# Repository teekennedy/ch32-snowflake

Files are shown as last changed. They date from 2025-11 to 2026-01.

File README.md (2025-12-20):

# CH32 Snowflake

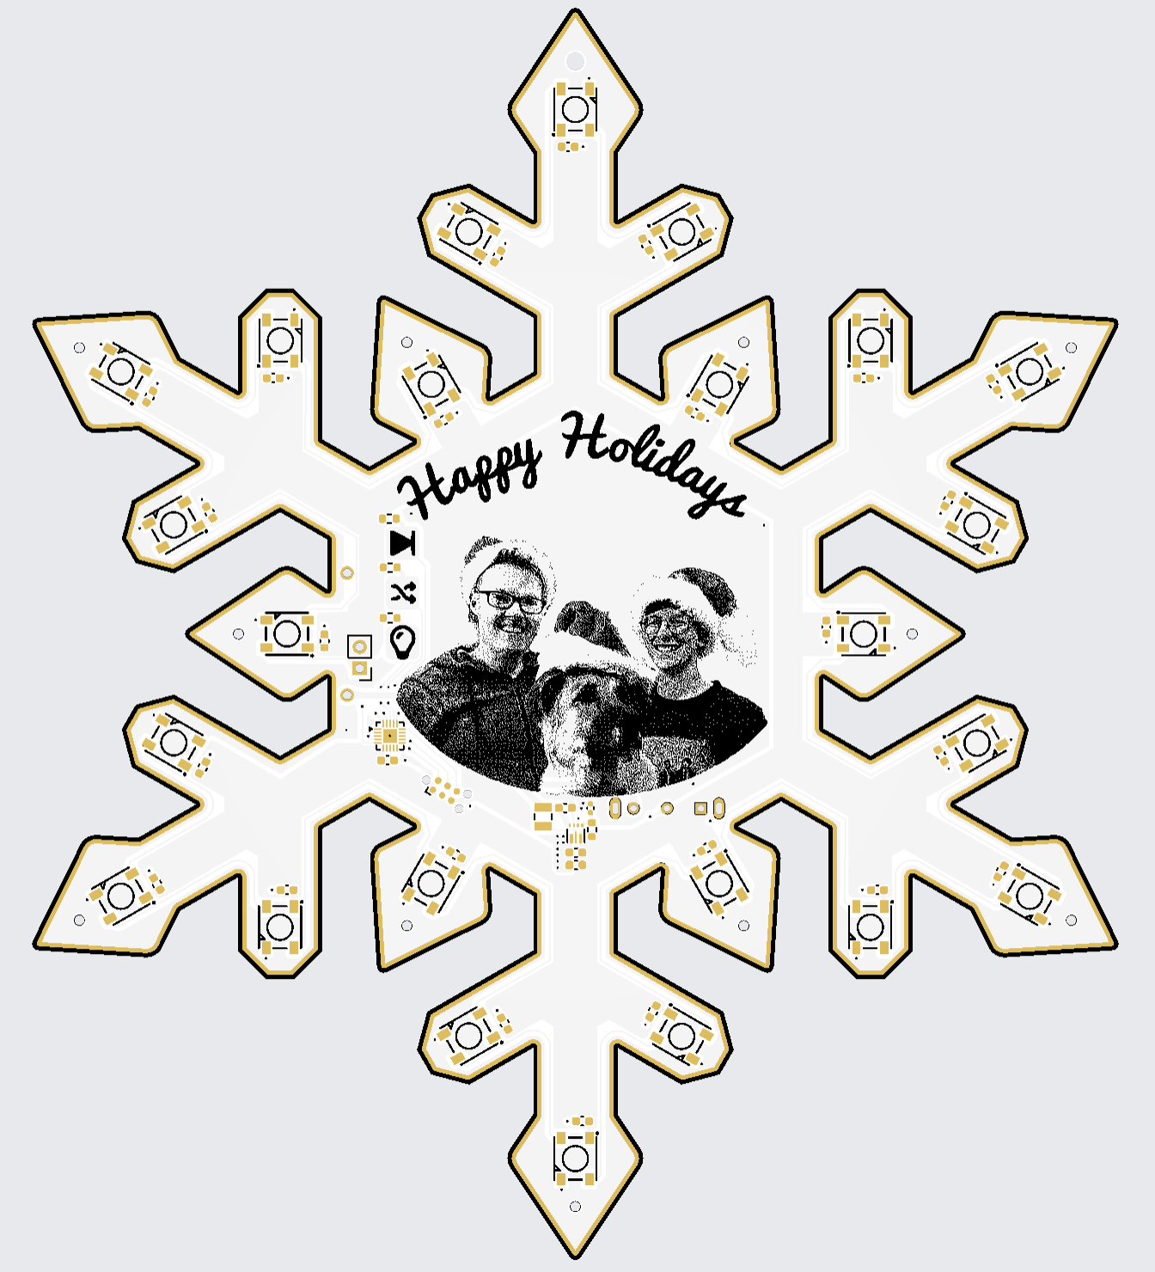
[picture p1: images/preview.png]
preview


A holiday snowflake with RGB LEDs, driven by the infamous CH32V003 microcontroller.

This is my first ever PCB design, and I borrowed heavily from [ch32-fireplace](https://github.com/johanwheeler/ch32-fireplace/tree/main) for snippets of schematic and code.

## PCB Shape

The snowflake shape was designed in OpenSCAD using the [BOSL2 library](https://github.com/BelfrySCAD/BOSL2).
If you want to view or make changes to the shape, I highly recommend installing the nightly version of openSCAD.

## KiCad Project

The KiCad project was designed with help from the [jlcpcb-tools plugin](https://github.com/Bouni/kicad-jlcpcb-tools).
If you plan to send this board to JLCPCB, be sure to import [corrections.csv](./board/jlcpcb/corrections.csv) before generating your pick and place file.
It has corrections for both the CH32V003 (90 degrees CCW rotation) and the TPS61002 boost converter (which is offset from where it should be).

I did my best to choose Basic parts where possible, to help keep the cost of the economic PCB assembly down.
Then I went with an ENIG coating and couldn't use economic PCBA anyway. Oh well.

## Firmware

In order to flash the firmware, you need to setup your build environment for [ch32fun](https://github.com/cnlohr/ch32fun).
See [their installation wiki](https://github.com/cnlohr/ch32fun/wiki/Installation) for instructions.

Next, build the `minichlink` utility.
Ensure the ch32fun submodule is initialized `git submodule update --init`.
Then, from the software/ch32fun/minichlink directory, run `make`.
If you have your RISC-V toolchain installed properly, it should build.

Now you can go to the software/src directory and run `make` to compile and flash the binary.

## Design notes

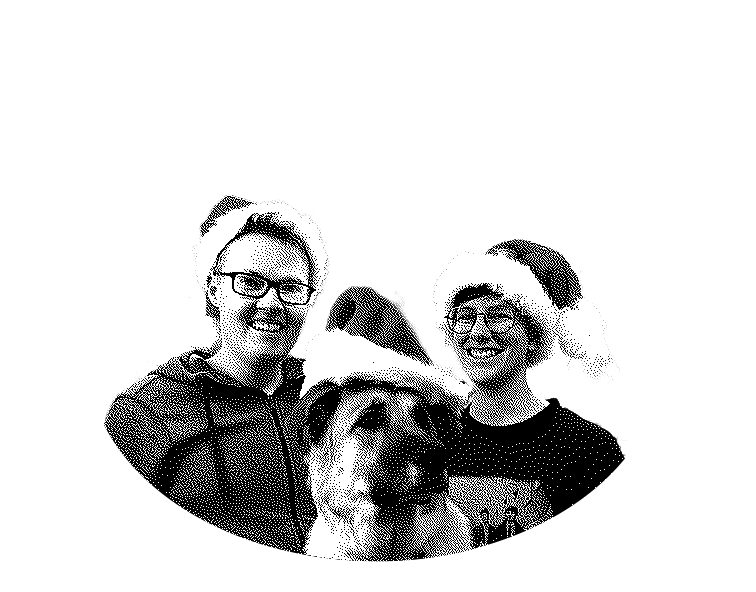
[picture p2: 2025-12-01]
images/graphics/front-silkscreen-ditherlicious.png

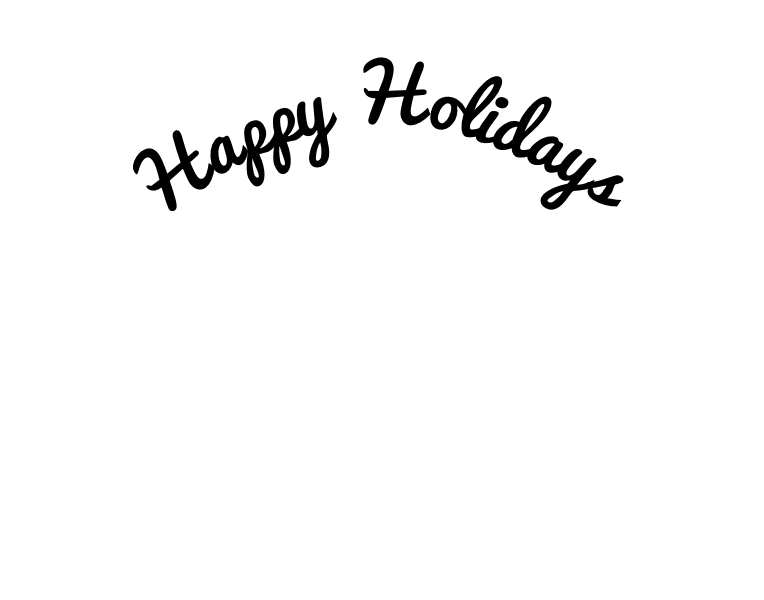
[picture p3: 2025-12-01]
images/graphics/front-silkscreen-text.png

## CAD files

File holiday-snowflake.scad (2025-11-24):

include <BOSL2/std.scad>

//visualization options
show_leds = false;
show_halos = false;
show_board = true;

$fn=16;

PHI = (1 + sqrt(5)) / 2; // =~ 1.618

branch_thickness = 10;
// shrinking overall diameter to account for diamond shapes added at tips
base_diameter = 150;
diameter = base_diameter - (branch_thickness * 1.2 * sqrt(2) * 1.5);
radius = diameter / 2;
secondary_branch_1_offset = radius*0.65;
secondary_branch_1_length = radius/3;

chamfer = branch_thickness / 3;
middle_diameter = 34;

// --- LED + halo params ---
led_size       = [5,5];
led_color      = "lightblue";
halo_color     = "lightyellow";   // outline color
halo_diameter  = middle_diameter/1.5;            // diameter of brightness ring
halo_width     = 0.8;           // thickness of the ring

// Module: centered LED with a thin circular outline ("brightness" halo)
module led_with_halo(
    size      = led_size,
    led_col   = led_color,
    halo_col  = halo_color,
    halo_d    = halo_diameter,
    halo_w    = halo_width
){
    up(1) {
        // LED body (centered rectangle)
        if (show_leds) color(led_col) rect(size);

        // Thin ring made by subtracting a slightly smaller circle
        halo_path = circle(d=halo_d);
        if (show_halos) color(halo_col) stroke(halo_path,closed=true);
    }
}

// the central hexagon of the snowflake
module central_hexagon(diameter) {
    if(show_board)
        regular_ngon(6, diameter);
//    rot_copies(n=6)
//        right(diameter - branch_thickness/PHI) led_with_halo();
}

module primary_branch(
    length,
){
    if(show_board) {
        rect([length, branch_thickness], anchor=LEFT);
        right(length) xscale(1.5) rect(branch_thickness*1.2, spin=45, rounding=1);
    }
    right(length) led_with_halo();
}

module secondary_branch(
    offset,
    length,
    led=true,
){
    if(show_board)
        for(ang=[60,-60])
            right(offset)
                rect([length, branch_thickness], chamfer=[chamfer,0,0,chamfer],spin=ang, anchor=LEFT);
    if (led)
        for(ang=[60,-60])
            right(offset)
                zrot(ang)
                    right(cos(ang)*length*2 - branch_thickness/PHI)
                        led_with_halo();
}

// When importing the LEDs into KiCAD (for easier alignment), the scale is somehow different from the snowflake.
// Adding these markings in the corners so both exports have the same bounding box.
//for(x=[base_diameter / -2, base_diameter / 2]) {
//    for(y=[base_diameter / -2, base_diameter / 2]) {
//        left(x) back(y) rect(0.2);
//    }
//}
// Rotated so it has vertical primary branches.
// This will make it easier to address the LEDs starting with the "North" branch.
zrot(90) {
    central_hexagon(middle_diameter);
    rot_copies(n=6) {
        primary_branch(radius);
        zrot(30) primary_branch(radius*1.1/2);
        secondary_branch(secondary_branch_1_offset, secondary_branch_1_length);
    }
}

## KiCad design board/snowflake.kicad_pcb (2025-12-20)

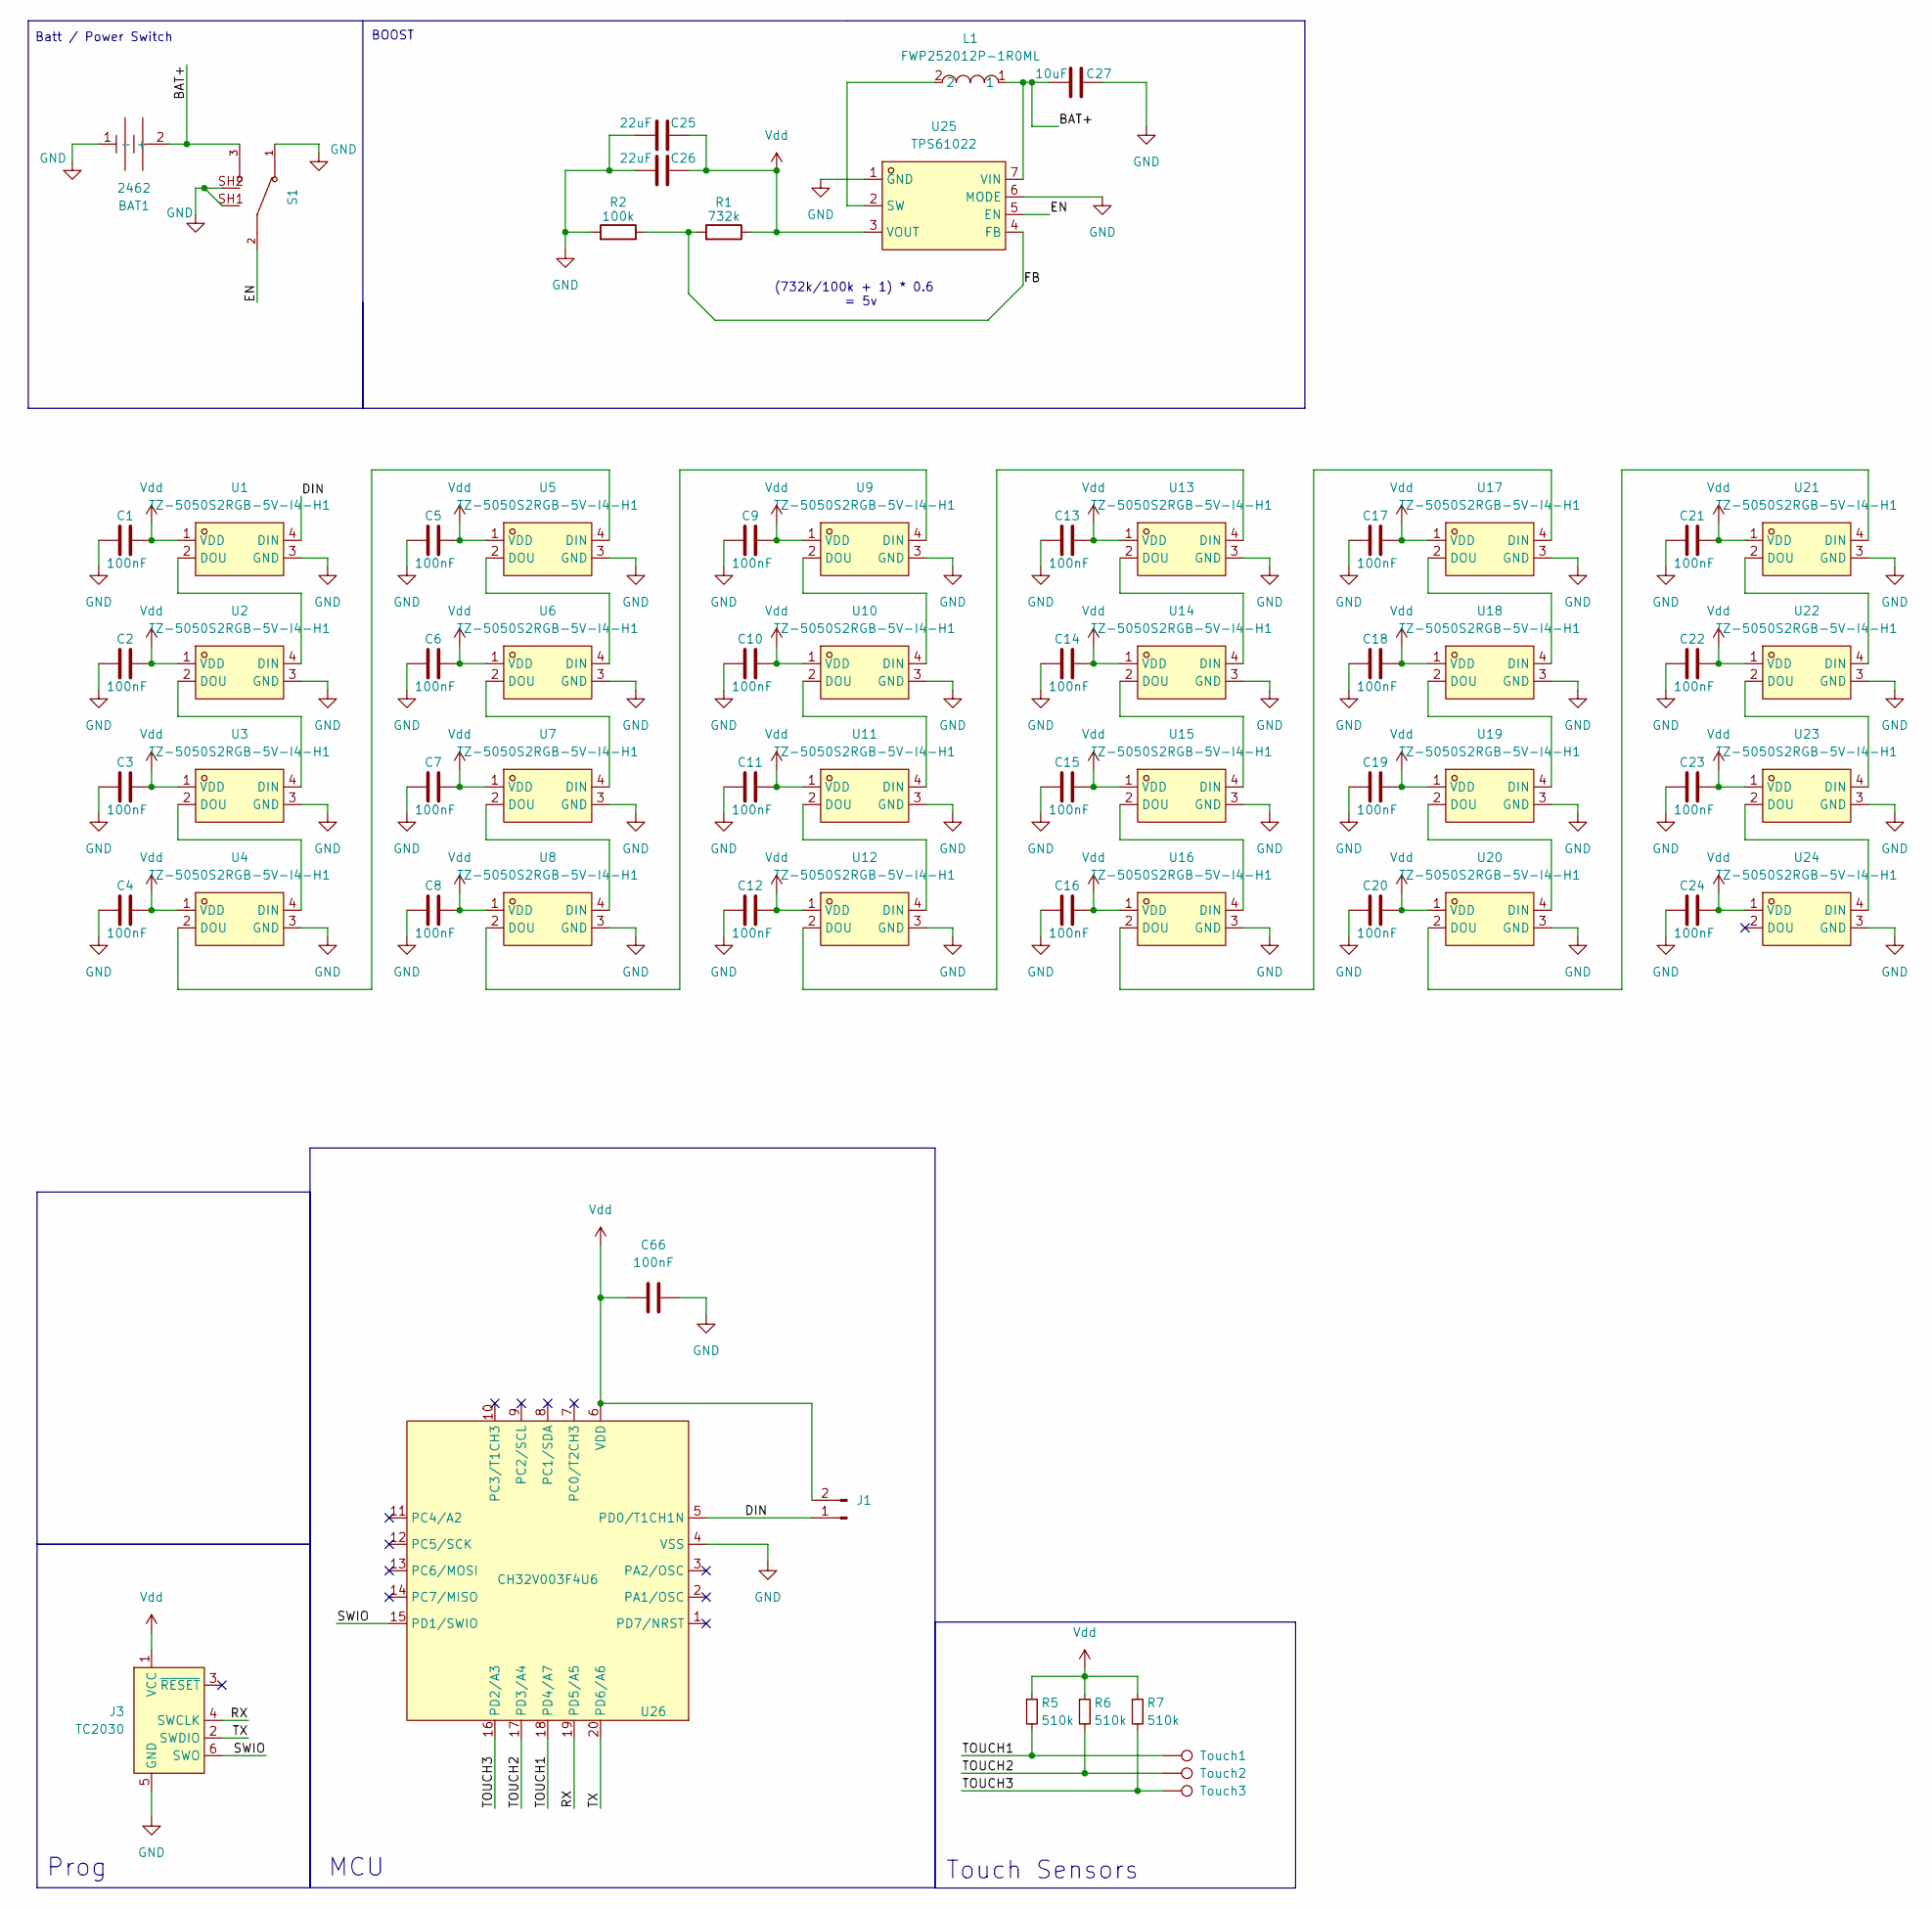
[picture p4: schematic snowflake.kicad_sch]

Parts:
BAT1: 2462; BAT-TH_2P-P14.50_2462; LCSC Part C3029547
C1, C2, C3, C4, C5, C6, C7, C8, C9, C10, C11, C12, C13, C14, C15, C16, C17, C18, C19, C20, C21, C22, C23, C24, C66: 100nF; C_0603_1608Metric; LCSC C14663
C25, C26: 22uF; C_0603_1608Metric; LCSC C59461
C27: 10uF; C_0603_1608Metric; LCSC C19702
J1: Conn_01x02_Pin; PinHeader_1x02_P2.54mm_Vertical
J3: TC2030; Tag-Connect_TC2030-IDC-NL_2x03_P1.27mm_Vertical
L1: FWP252012P-1R0ML; IND-SMD_L2.5-W2.0_YXMBL252010P; LCSC C5179444
R1: 732k; R_0603_1608Metric; LCSC C22961
R2: 100k; R_0402_1005Metric; LCSC C25741
R5, R6, R7: 510k; R_0603_1608Metric; MPN C23203; LCSC C23192
S1: SLW-1277545-3A-RA-N-D; SW_SLW-1277545-3A-RA-N-D; PARTREV 1.01
TP5: Touch1; TouchPad
TP6: Touch2; TouchPad
TP7: Touch3; TouchPad
U1, U2, U3, U4, U5, U6, U7, U8, U9, U10, U11, U12, U13, U14, U15, U16, U17, U18, U19, U20, U21, U22, U23, U24: TZ-5050S2RGB-5V-I4-H1; LED-SMD_4P-L5.0-W5.0-TL_WS2812B-B; LCSC C26167850
U25: TPS61022; VQFN-7_L2.0-W2.0-P0.55-TL_RWU; LCSC C915088
U26: CH32V003F4U6; QFN-20_L3.0-W3.0-P0.40-TL-EP1.7; MPN C5299908; LCSC C5299908

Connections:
/BAT+: BAT1.2 (+), C27.2, L1.1, S1.3, U25.7 (VIN)
/DIN: J1.1, U1.4 (DIN), U26.5 (PD0/T1CH1N)
/EN: S1.2, U25.5 (EN)
/FB: R1.2, R2.1, U25.4 (FB)
/RX: J3.4 (SWCLK), U26.19 (PD5/A5)
/SWIO: J3.6 (SWO), U26.15 (PD1/SWIO)
/TOUCH1: R5.2, TP5.1, U26.18 (PD4/A7)
/TOUCH2: R6.2, TP6.1, U26.17 (PD3/A4)
/TOUCH3: R7.2, TP7.1, U26.16 (PD2/A3)
/TX: J3.2 (SWDIO), U26.20 (PD6/A6)
GND: BAT1.1 (-), C1.1, C2.1, C3.1, C4.1, C5.1, C6.1, C7.1, C8.1, C9.1, C10.1, C11.1, C12.1, C13.1, C14.1, C15.1, C16.1, C17.1, C18.1, C19.1, C20.1, C21.1, C22.1, C23.1, C24.1, C25.2, C26.2, C27.1, C66.2, J3.5 (GND), R2.2, S1.1, S1.SH1, S1.SH2, U1.3 (GND), U2.3 (GND), U3.3 (GND), U4.3 (GND), U5.3 (GND), U6.3 (GND), U7.3 (GND), U8.3 (GND), U9.3 (GND), U10.3 (GND), U11.3 (GND), U12.3 (GND), U13.3 (GND), U14.3 (GND), U15.3 (GND), U16.3 (GND), U17.3 (GND), U18.3 (GND), U19.3 (GND), U20.3 (GND), U21.3 (GND), U22.3 (GND), U23.3 (GND), U24.3 (GND), U25.1 (GND), U25.6 (MODE), U26.4 (VSS), U26.21 (VSS)
unnamed: U1.2 (DOU), U2.4 (DIN)
unnamed: U2.2 (DOU), U3.4 (DIN)
unnamed: U3.2 (DOU), U4.4 (DIN)
unnamed: U4.2 (DOU), U5.4 (DIN)
unnamed: U5.2 (DOU), U6.4 (DIN)
unnamed: U6.2 (DOU), U7.4 (DIN)
unnamed: U7.2 (DOU), U8.4 (DIN)
unnamed: U8.2 (DOU), U9.4 (DIN)
unnamed: U9.2 (DOU), U10.4 (DIN)
unnamed: U10.2 (DOU), U11.4 (DIN)
unnamed: U11.2 (DOU), U12.4 (DIN)
unnamed: U12.2 (DOU), U13.4 (DIN)
unnamed: U13.2 (DOU), U14.4 (DIN)
unnamed: U14.2 (DOU), U15.4 (DIN)
unnamed: U15.2 (DOU), U16.4 (DIN)
unnamed: U16.2 (DOU), U17.4 (DIN)
unnamed: U17.2 (DOU), U18.4 (DIN)
unnamed: U18.2 (DOU), U19.4 (DIN)
unnamed: U19.2 (DOU), U20.4 (DIN)
unnamed: U20.2 (DOU), U21.4 (DIN)
unnamed: U21.2 (DOU), U22.4 (DIN)
unnamed: U22.2 (DOU), U23.4 (DIN)
unnamed: U23.2 (DOU), U24.4 (DIN)
unnamed: L1.2, U25.2 (SW)
Vdd: C1.2, C2.2, C3.2, C4.2, C5.2, C6.2, C7.2, C8.2, C9.2, C10.2, C11.2, C12.2, C13.2, C14.2, C15.2, C16.2, C17.2, C18.2, C19.2, C20.2, C21.2, C22.2, C23.2, C24.2, C25.1, C26.1, C66.1, J1.2, J3.1 (VCC), R1.1, R5.1, R6.1, R7.1, U1.1 (VDD), U2.1 (VDD), U3.1 (VDD), U4.1 (VDD), U5.1 (VDD), U6.1 (VDD), U7.1 (VDD), U8.1 (VDD), U9.1 (VDD), U10.1 (VDD), U11.1 (VDD), U12.1 (VDD), U13.1 (VDD), U14.1 (VDD), U15.1 (VDD), U16.1 (VDD), U17.1 (VDD), U18.1 (VDD), U19.1 (VDD), U20.1 (VDD), U21.1 (VDD), U22.1 (VDD), U23.1 (VDD), U24.1 (VDD), U25.3 (VOUT), U26.6 (VDD)

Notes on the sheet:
Batt / Power Switch
BOOST
Prog
Touch Sensors
(732k/100k + 1) * 0.6 = 5v
MCU

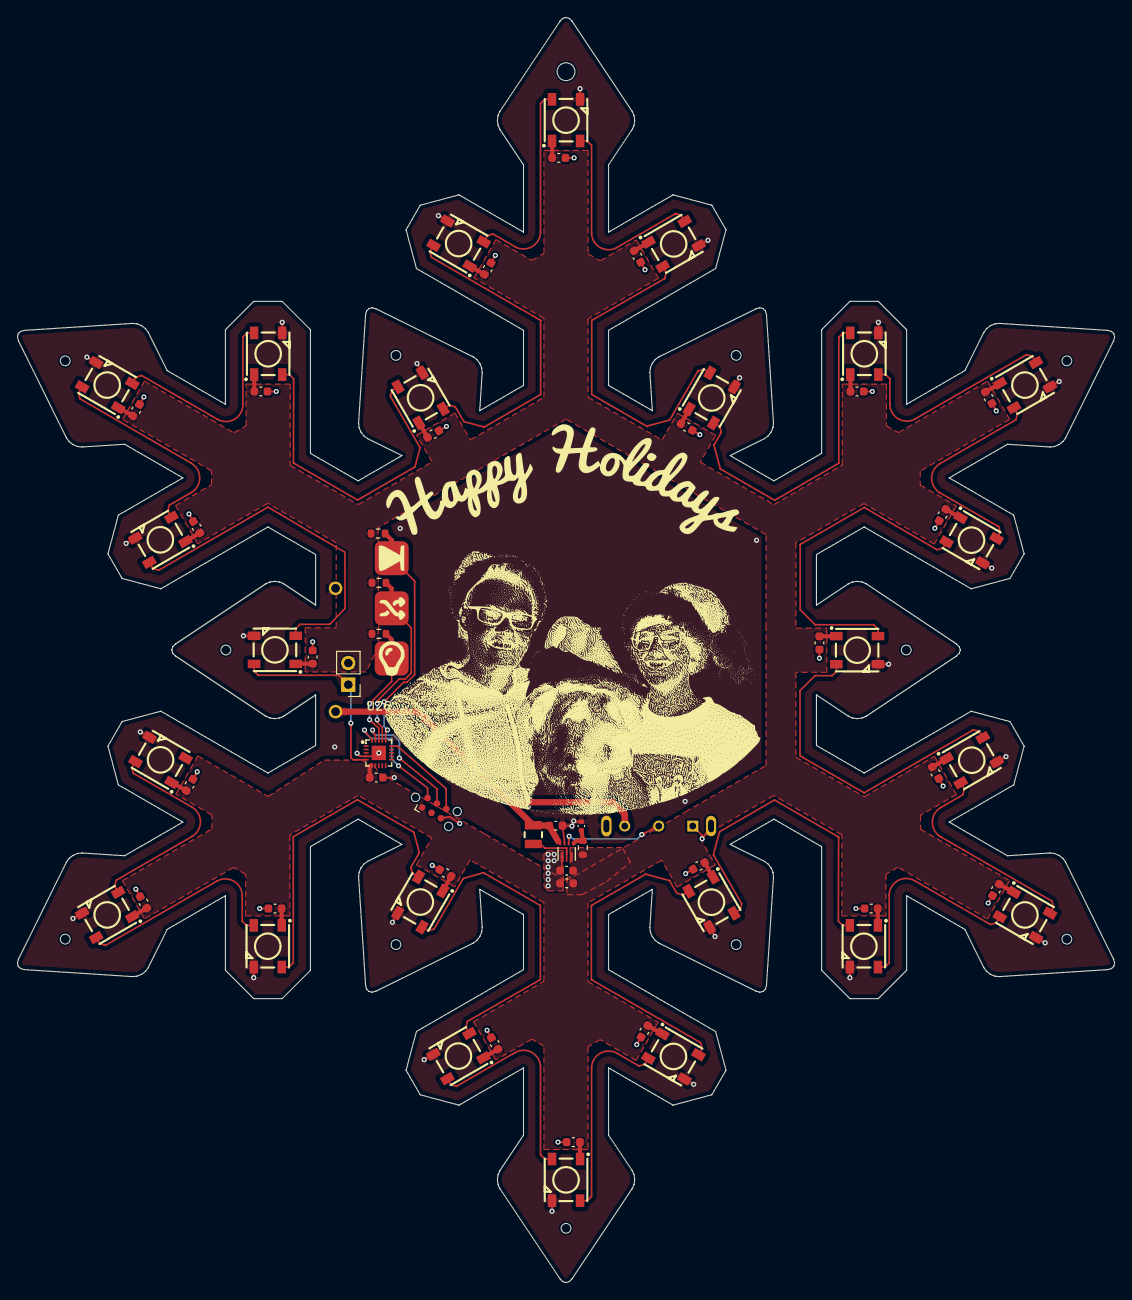
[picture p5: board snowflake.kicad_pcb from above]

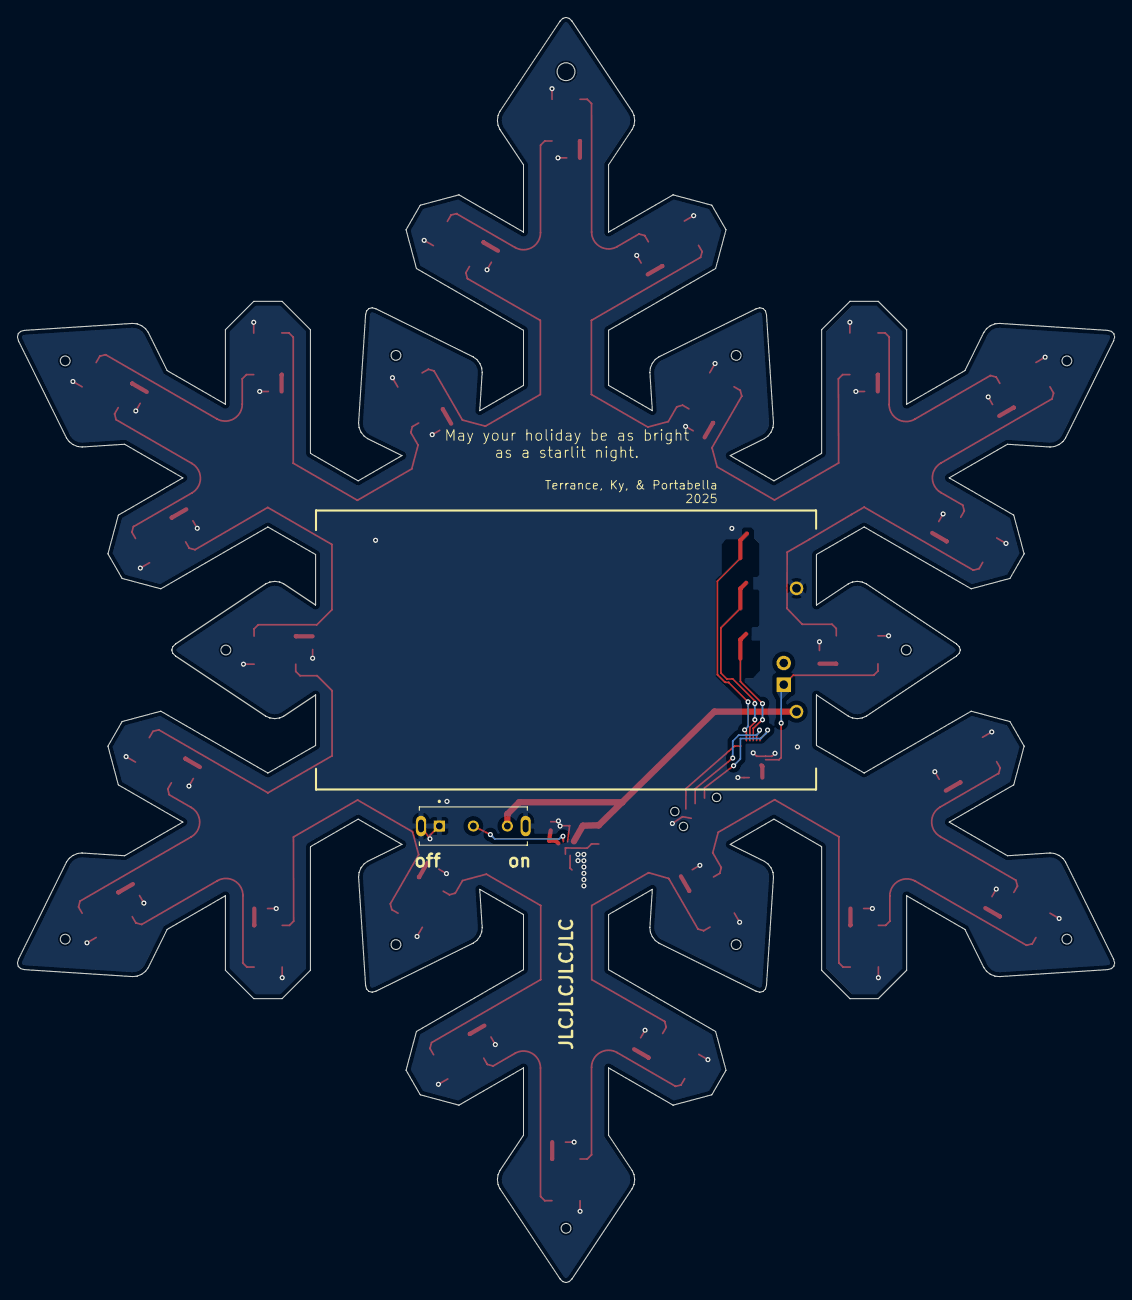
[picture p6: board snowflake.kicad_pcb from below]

Board: 2 copper layers, 129.0 x 148.8 mm, 67 parts (2 on the bottom side), 36 nets.

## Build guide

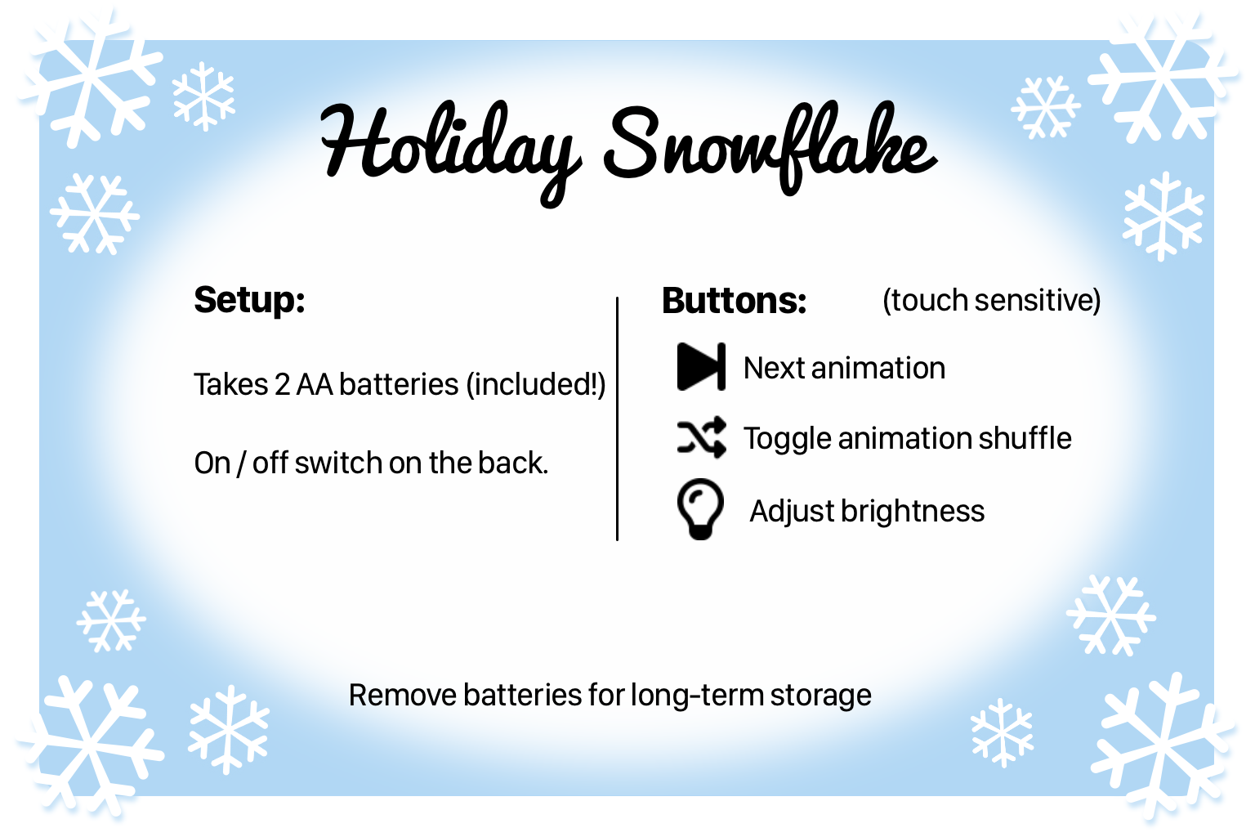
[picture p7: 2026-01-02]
images/Instructions.png

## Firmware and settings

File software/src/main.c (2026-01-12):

#include "ch32fun.h"
#include <stdio.h>
#include "tz_5050s2_driver.h"
#include "animations.h"
#include "touch.h"
#include "nvram.h"

// Default values for settings
uint8_t ledFuncIndex = 0;
uint8_t ledBrightness = 3;
bool shuffleOn = true;

int main()
{
	SystemInit();

	funGpioInitAll(); // Enable GPIOs
	
	buttons_init();
	RGBInit(PIN_RGB);

	int frame = 0;
	led_fn_t ledFuncs[] = {
		GetLEDChristmasLights,
		GetLEDTwinkleIce,
		GetLEDTwinkleRedGreen,
		GetLEDShootingStar,
		GetLEDRainbow,
		// GetLEDAllOff,
	};
	const uint32_t ledFuncCount = sizeof(ledFuncs) / sizeof(ledFuncs[0]);
	NvramSettings nvram_settings;
	if (NvramLoadSettings(&nvram_settings)) {
		ledBrightness = nvram_settings.led_brightness;
		ledFuncIndex = nvram_settings.led_func_index % ledFuncCount;
		shuffleOn = nvram_settings.shuffle_on;
	}
	uint8_t persisted_led_index = ledFuncIndex;
	buttonPress_t lastButton = buttonNone;
	const uint32_t frame_delay_ticks = 67U * DELAY_MS_TIME;
	const uint32_t shuffle_interval_ticks = DELAY_SEC_COUNT(60);
	uint32_t shuffle_deadline = SysTick->CNT + shuffle_interval_ticks;
	while(1)
	{
		uint32_t frame_start = SysTick->CNT;
		uint32_t targend = frame_start + frame_delay_ticks;
		if (shuffleOn && ((int32_t)(frame_start - shuffle_deadline)) >= 0) {
			ledFuncIndex = (uint8_t)((ledFuncIndex + 1U) % ledFuncCount);
			shuffle_deadline = frame_start + shuffle_interval_ticks;
		}
		RGBSend(PORT_RGB, ledFuncs[ledFuncIndex], frame, ledBrightness + 2);
		frame++;
		buttonPress_t button = buttons_read();
		if (button != lastButton) {
			lastButton = button;
			// printf("Button pressed: %x", button);
			bool settings_changed = false;
			bool save_led_index = true;
			bool reset_shuffle_timer = false;
			switch (button) {
				case buttonNext:
					ledFuncIndex = (uint8_t)((ledFuncIndex + 1U) % ledFuncCount);
					if (shuffleOn) {
						save_led_index = false;
						reset_shuffle_timer = true;
					} else {
						settings_changed = true;
					}
					break;
				case buttonShuffle:
				    shuffleOn = !shuffleOn;
				    settings_changed = true;
				    reset_shuffle_timer = shuffleOn;
				    // Give user feedback that shuffle button was pressed
				    if (shuffleOn) {
						RGBSend(PORT_RGB, GetLEDShuffleOn, frame, ledBrightness + 1);
				    } else {
						RGBSend(PORT_RGB, GetLEDShuffleOff, frame, ledBrightness + 1);
				    }
				    Delay_Ms(250);
				    break;
				case buttonBrightness:
				    ledBrightness--;
				    if (ledBrightness >= 4) {
				    	ledBrightness = 3;
				    }
				    settings_changed = true;
				    if (shuffleOn) {
				    	save_led_index = false;
				    }
				default:
					break;
			}
			if (reset_shuffle_timer) {
				shuffle_deadline = SysTick->CNT + shuffle_interval_ticks;
			}
			if (settings_changed) {
				uint8_t target_led_index = save_led_index ? ledFuncIndex : persisted_led_index;
				NvramSettings new_settings = {
					.led_brightness = ledBrightness,
					.led_func_index = target_led_index,
					.shuffle_on = shuffleOn ? 1U : 0U,
				};
				NvramSaveSettings(&new_settings);
				if (save_led_index) {
					persisted_led_index = ledFuncIndex;
				}
			}
		}
		while (((int32_t)(SysTick->CNT - targend)) < 0) {
			;
		}
	}
}

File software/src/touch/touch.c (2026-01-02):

#include "touch.h"
#include "ch32fun.h"
#include <stdint.h>

uint32_t endtime;

buttonPress_t last_button = buttonNone;

void EXTI7_0_IRQHandler(void) __attribute__((interrupt));
void EXTI7_0_IRQHandler(void)
{
    endtime = SysTick->CNT;
    EXTI->INTFR = 0xffffffff;
}

#define GPIOPortByBase(i) ((GPIO_TypeDef *)(GPIOA_BASE + 0x0400 * (i)))

// The "port" is:
// 0 for Port A
// 1 for Port B
// 2 for Port C
// 3 for Port D
int MeasureTouch(int portno, int pin, int pu_mode)
{
    uint32_t starttime;
    GPIO_TypeDef *port = GPIOPortByBase(portno);
    uint32_t pinx4 = pin << 2;

    // Mask out just our specific port.  This way we don't interfere with other
    // stuff that may be on this port.
    uint32_t base = port->CFGLR & (~(0xf << pinx4));

    // Mode for CFGLR when asserted.
    uint32_t setmode = base | (GPIO_CFGLR_OUT_2Mhz_PP) << (pinx4);

    // Mode for CFGLR when it drifts.
    uint32_t releasemode = base | (pu_mode) << (pinx4);

    // Assert pin
    port->CFGLR = setmode;
    port->BSHR = 1 << (pin + 16);

    // Setup pin-change-interrupt.  This will trigger when the voltage on the
    // pin rises above the  schmitt trigger threshold.
    AFIO->EXTICR = portno << (pin * 2);
    EXTI->INTENR = 0xffffffff; // Enable EXT3
    EXTI->RTENR = 0xffffffff;  // Rising edge trigger

    // Tricky, we want the release to happen at an un-aligned address.
    // This actually doubles our touch sensor resolution.
    asm volatile(".balign 4; c.nop");
    port->CFGLR = releasemode;
    starttime = SysTick->CNT;
    endtime = starttime + 384;
    port->BSHR = 1 << (pin);

// Allow up to 384 cycles for the pin to change.
#define DELAY8 \
    asm volatile("c.nop;c.nop;c.nop;c.nop;c.nop;c.nop;c.nop;c.nop;");
    DELAY8 DELAY8 DELAY8 DELAY8 DELAY8 DELAY8 DELAY8 DELAY8
    DELAY8 DELAY8 DELAY8 DELAY8 DELAY8 DELAY8 DELAY8 DELAY8
    DELAY8 DELAY8 DELAY8 DELAY8 DELAY8 DELAY8 DELAY8 DELAY8
    DELAY8 DELAY8 DELAY8 DELAY8 DELAY8 DELAY8 DELAY8 DELAY8
    DELAY8 DELAY8 DELAY8 DELAY8 DELAY8 DELAY8 DELAY8 DELAY8
    DELAY8 DELAY8 DELAY8 DELAY8 DELAY8 DELAY8 DELAY8 DELAY8

    // Optimization: If you did the nop sled in assembly, the interrupt could scoot to the end

    // Disable EXTI
    EXTI->INTENR = 0;

    // Optional assert pin when done to prevent it from noodling around.
    // port->CFGLR = setmode;
    // port->BSHR = 1<<(pin+16);

    return endtime - starttime;
}

#ifndef TOUCH_DEBUG
#define TOUCH_DEBUG 0
#endif

#if TOUCH_DEBUG
#include <stdio.h>
#endif

#define TOUCH_PAD_COUNT 3
#define TOUCH_BASELINE_SAMPLES 32
#define TOUCH_THRESHOLD_OFFSET 6

static const uint8_t touch_ports[TOUCH_PAD_COUNT] = { 3, 3, 3 };
static const uint8_t touch_pins[TOUCH_PAD_COUNT] = { 2, 3, 4 };
static const buttonPress_t touch_buttons[TOUCH_PAD_COUNT] = {
    buttonNext,
    buttonShuffle,
    buttonBrightness,
};

static uint16_t touch_baseline[TOUCH_PAD_COUNT];

static uint16_t Median3(uint16_t a, uint16_t b, uint16_t c)
{
    if (a > b) {
        uint16_t tmp = a;
        a = b;
        b = tmp;
    }
    if (b > c) {
        uint16_t tmp = b;
        b = c;
        c = tmp;
    }
    if (a > b) {
        uint16_t tmp = a;
        a = b;
        b = tmp;
    }
    return b;
}

static void TouchCalibrate(void)
{
    for (int pad = 0; pad < TOUCH_PAD_COUNT; pad++) {
        uint32_t sum = 0;
        for (int sample = 0; sample < TOUCH_BASELINE_SAMPLES; sample++) {
            sum += MeasureTouch(touch_ports[pad], touch_pins[pad], GPIO_CFGLR_IN_FLOAT);
        }
        touch_baseline[pad] = (uint16_t)(sum / TOUCH_BASELINE_SAMPLES);
    }
}

void buttons_init(){
    RCC->APB2PCENR |= RCC_APB2Periph_GPIOD | RCC_APB2Periph_AFIO;

    // enable pin-change-interrupt.
    NVIC_EnableIRQ(EXTI7_0_IRQn);

    Delay_Ms(20);
    TouchCalibrate();
}

buttonPress_t buttons_read() {
    buttonPress_t read = buttonNone;
    uint16_t values[TOUCH_PAD_COUNT];

    for (int pad = 0; pad < TOUCH_PAD_COUNT; pad++) {
        uint16_t a = MeasureTouch(touch_ports[pad], touch_pins[pad], GPIO_CFGLR_IN_FLOAT);
        uint16_t b = MeasureTouch(touch_ports[pad], touch_pins[pad], GPIO_CFGLR_IN_FLOAT);
        uint16_t c = MeasureTouch(touch_ports[pad], touch_pins[pad], GPIO_CFGLR_IN_FLOAT);
        values[pad] = Median3(a, b, c);
        uint16_t threshold = touch_baseline[pad] + TOUCH_THRESHOLD_OFFSET;
        if (values[pad] >= threshold) {
            read |= touch_buttons[pad];
        }
    }

#if TOUCH_DEBUG
    static uint32_t next_debug = 0;
    uint32_t now = SysTick->CNT;
    if (((int32_t)(now - next_debug)) >= 0) {
        printf("touch raw: %u %u %u base: %u %u %u\n",
               values[0], values[1], values[2],
               touch_baseline[0], touch_baseline[1], touch_baseline[2]);
        next_debug = now + (DELAY_MS_TIME * 200U);
    }
#endif

    return read;
}

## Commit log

2025-11-08 snowflake shape with evenly spaced leds
    [holiday-snowflake.scad]
2025-11-10 v1 snowflake shape
    [holiday-snowflake.scad]
2025-11-10 Modularize hexagon shape
    [holiday-snowflake.scad]
2025-11-10 About to create rotational array of LEDs
    [holiday-snowflake.scad, snowflake.kicad_pcb, snowflake.kicad_sch]
2025-11-11 2/6 branches
    [snowflake.kicad_pcb, snowflake.kicad_sch]
2025-11-11 Add JLCPCB Part Numbers
    [snowflake.kicad_pcb, snowflake.kicad_sch]
2025-11-11 Submitted for cost estimate from JLCPCB
    [snowflake.kicad_pcb, snowflake.kicad_sch]
2025-11-11 The nets are happy again
    [holiday-snowflake.scad, snowflake.kicad_pcb, snowflake.kicad_sch]
2025-11-13 Use zones instead of traces for +5V
    [snowflake.kicad_pcb, snowflake.kicad_sch]
2025-11-13 First prototype
    [snowflake.kicad_pcb, snowflake.kicad_sch]
2025-11-13 Add mounting and tooling holes
    [snowflake.kicad_pcb]
2025-11-13 Use basic parts, fix boost converter positioning
    [snowflake.kicad_pcb, snowflake.kicad_sch]
2025-11-13 Add more vias to try and keep the ground planes even
    [snowflake.kicad_pcb]
2025-11-14 Add teardrops to vias and PTH pads, mask border
    [snowflake.kicad_pcb]
2025-11-24 put everything on one side
    [holiday-snowflake.scad, snowflake.kicad_pcb, snowflake.kicad_sch]
2025-11-26 Update PCB and customize some footprints
    [snowflake.kicad_pcb, snowflake.kicad_sch]
2025-11-26 Add readme, update rgb led driver
2025-12-01 Add graphics to board
    [snowflake.kicad_pcb, snowflake.kicad_sch]
2025-12-01 Final board updates before sending
    [snowflake.kicad_pcb, snowflake.kicad_sch]
2025-12-01 Catch what would have been a huge mistake
    [snowflake.kicad_pcb, snowflake.kicad_sch]
2025-12-01 Cleanup power switch traces
    [snowflake.kicad_pcb, snowflake.kicad_sch]
2025-12-01 Submitted for production
    [snowflake.kicad_pcb]
2025-12-03 Add missing 3d file for CH32v003 footprint
    [snowflake.kicad_pcb, snowflake.kicad_sch]
2025-12-12 Got as far as I could with DMA-based LED control
2025-12-20 Fix R1 part number
    [snowflake.kicad_pcb]
2025-12-20 Add JLCPCB pick and place corrections.csv
    [corrections.csv]
2025-12-20 Update variables based on button press
2025-12-20 Move touch code to subfolder, fix animations crashing
    [main.c, touch.c]
2025-12-21 Make frame timing consistent across animations
2026-01-02 Make touch button detection more robust
